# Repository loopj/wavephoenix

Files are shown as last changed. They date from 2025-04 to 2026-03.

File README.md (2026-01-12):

<h1 align="center">
    WavePhoenix
</h1>

<p align="center">
    Open-source implementation of the Nintendo WaveBird receiver using Silicon Labs Wireless Gecko SoCs
</p>
<p align="center">
    
</p>

<p align="center">
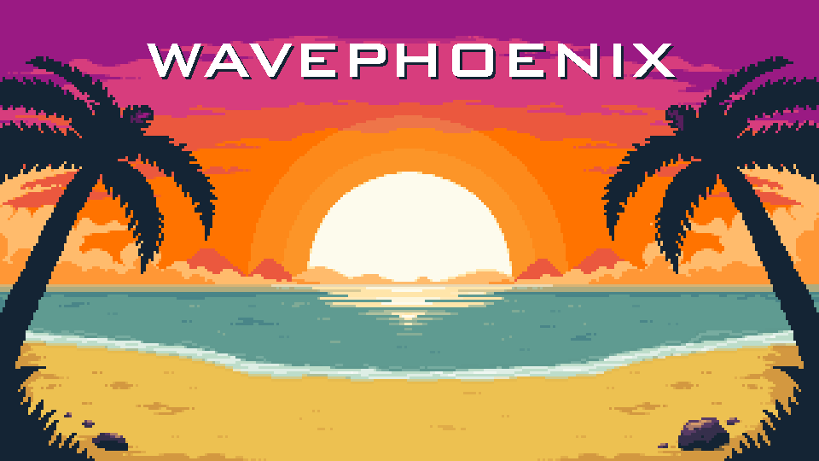
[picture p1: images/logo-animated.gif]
WavePhoenix
    
</p>

## Motivation

The WaveBird controller is, in my opinion, one of the best controllers ever made. It is wireless, has an insane battery life, and is very comfortable to hold. The WaveBird set a new standard for wireless controllers. It was the first major console controller to use radio frequency (RF) technology, providing a reliable, lag-free connection that didn't require line-of-sight, unlike infrared controllers.

Unfortunately, Nintendo stopped producing the WaveBird more than a decade ago, causing a dwindling supply of controllers and, especially, receivers. Given the decreasing supply of receivers and the increasing resale prices, I decided to design my own from scratch.

## Features

The reference implementation of WavePhoenix includes the following features:

- Full compatibility with the original WaveBird controller
- One-button virtual pairing, like modern wireless devices
- Status LED to indicate pairing status and radio activity
- Over-the-air firmware updates via Bluetooth
- Open source hardware and firmware
- 3D printable case

## Buying a WavePhoenix

Don't want to build your own? A number of vendors are now selling pre-assembled WavePhoenix receivers!

- [Laser Bear Industries](https://www.laserbear.net/products/wavephoenix-replacement-wavebird-gamecube-receiver) - US-based seller, custom enclosure and PCB by Greg
- [Colester Productions](https://shop.colesterproductions.com/product/wave-phoenix) - US-based seller, uses my original PCB and [
SadSnifit's fantastic case](https://makerworld.com/en/models/1463984-wavephoenix-wavebird-shell)
- [Various AliExpress sellers](https://www.aliexpress.us/w/wholesale-%22wavephoenix%22.html)

## Building a WavePhoenix

The bare minimum hardware needed to build a WavePhoenix is a EFR32BG22 radio module (such as the [RF-BM-BG22C3](https://www.rfstariot.com/rf-bm-bg22c3-efr32bg22-bluetooth-module_p93.html)), a GameCube controller connector, and 3 wires!

Since most people prefer a more streamlined solution, I designed a custom PCB and 3D-printable case called the *Mini Receiver*.

You can find detailed build instructions in the [hardware/mini-receiver](hardware/mini-receiver) directory.

## Firmware Components

The firmware for WavePhoenix is composed of the following components:

- [`libwavebird`](https://github.com/loopj/libwavebird) - my implementation of Nintendo's WaveBird protocol for Silicon Labs Gecko SoCs
- [`libjoybus`](https://github.com/loopj/libjoybus) - my implementation of the Joybus protocol used by N64 and GameCube controllers
- [`firmware/app`](firmware/app) - the main app firmware; a reference implementation of a WaveBird receiver
- [`firmware/bootloader`](firmware/bootloader) - bootloader to provide over-the-air firmware updates via Bluetooth

## Worklog

Check out the [worklog](WORKLOG.md) for a detailed history of the development of the WavePhoenix project.

## Special Thanks

- [Sam Edwards](https://github.com/CFSworks) for his incredible WaveBird reverse engineering documentation, which was essential in getting this working
- [Jeff Longo](https://jefflongo.dev) - for his detailed GameCube controller protocol documentation
- [Aurelio Mannara](https://github.com/Aurelio92) - for open sourcing GC+, another great reference for the GameCube controller protocol
- [YveltalGriffin](https://bsky.app/profile/mks.bsky.social) - for help and advice along the way, and helping me figure out those mysterious origin packets
- piotref1 - for being the very first person to build a WavePhoenix receiver and provide feedback, a true early adopter!
- Everyone in the incredible [BitBuilt community](https://bitbuilt.net/) for their support and encouragement throughout this project

## License

WavePhoenix is a permissively licensed open source project.

The firmware is licensed under the [MIT License](firmware/LICENSE).

The hardware is licensed under the [Solderpad Hardware License v2.1](hardware/LICENSE).

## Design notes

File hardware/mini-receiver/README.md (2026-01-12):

# WavePhoenix Mini Receiver

The WavePhoenix Mini Receiver is a small, low-cost WaveBird receiver replacement. It has been designed to be as cheap as possible (~$4 in parts) and simple to build.

The receiver uses a cheap, off-the-shelf wireless module (the [RF-BM-BG22C3](https://www.rfstariot.com/rf-bm-bg22c3-efr32bg22-bluetooth-module_p93.html)), which can either be hand-wired, or assembled onto a custom PCB.

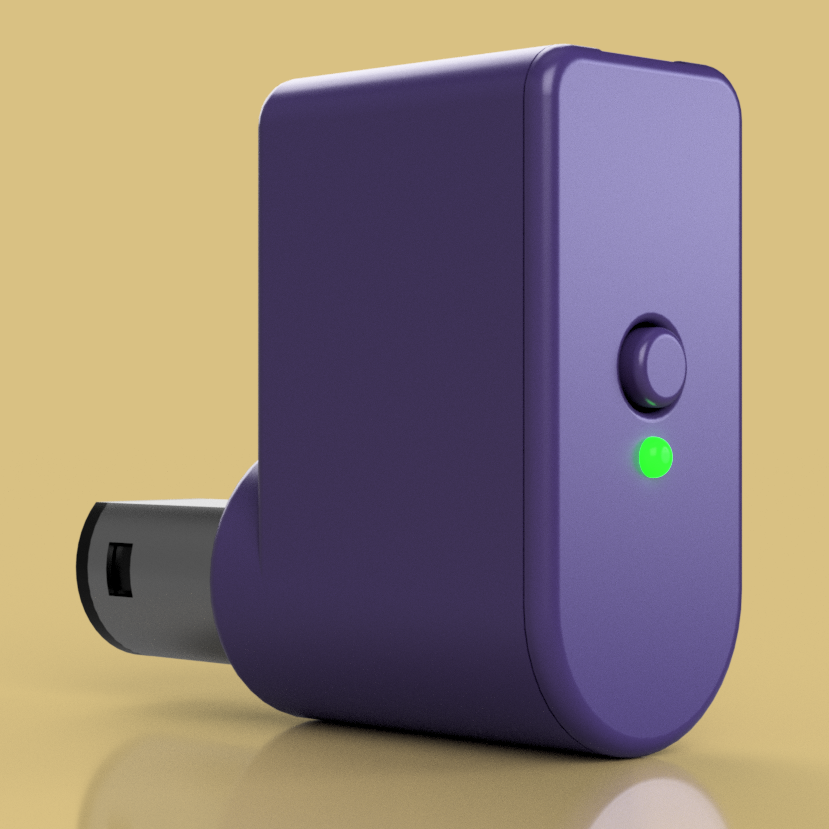
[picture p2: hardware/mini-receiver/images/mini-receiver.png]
WavePhoenix Mini Receiver
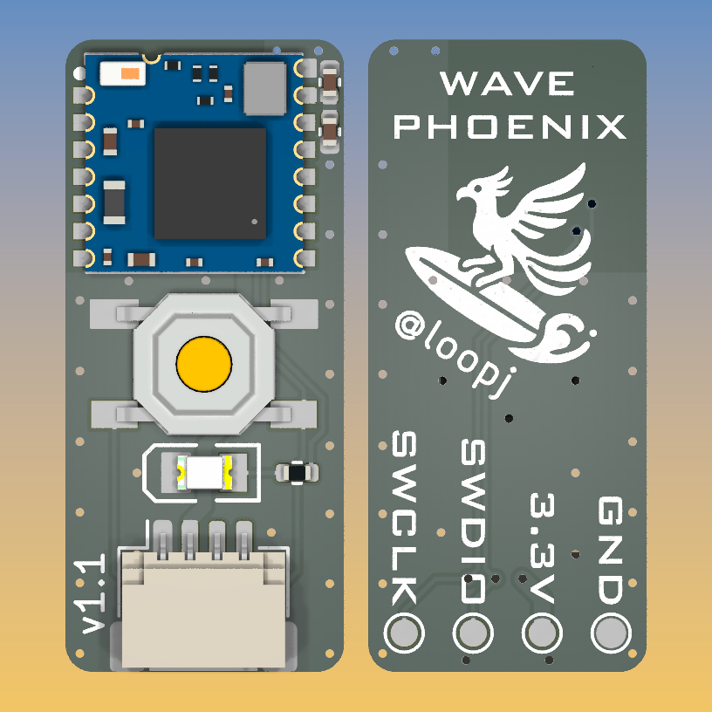
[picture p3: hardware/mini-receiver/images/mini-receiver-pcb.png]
WavePhoenix Mini Receiver
 

## Build Guide

### Parts

- Assembled Mini Receiver PCB - (see [PCB](#pcb))
- 3D printed case - (see [Case](#case))
- GameCube male connector - ([AliExpress](https://www.aliexpress.us/item/3256804501860592.html), [Alibaba](https://www.alibaba.com/product-detail/NGC-Gamecube-Male-Connector_1600107604838.html), [eBay](https://www.ebay.com/itm/354372477064))
- JST-SH 4-Pin connector with pre-crimped cable - ([AliExpress](https://www.aliexpress.us/item/3256803952186380.html), [Amazon](https://www.amazon.com/dp/B0D9WMLZ7B/))
- 1.5mm PMMA fiber cable - ([AliExpress](https://www.aliexpress.us/item/3256806278563564.html)) *or* 1.5mm diameter x 4mm light pipe - ([AliExpress](https://www.aliexpress.us/item/3256801194682892.html))
- Crimping tool or soldering iron (depending on the your connector type)

### Assembly

- Assemble the JST-SH to GameCube connector cable - (see [Cable](#cable))
- Flash the firmware - (see [Initial Firmware Flashing](#initial-firmware-flashing))
- Insert the GameCube connector into the case until it clicks into place
- Connect the JST-SH connector to the PCB
- Insert the PCB into the case, ensuring the LED and switch are aligned with the holes in the case, it should click into place
- Insert the light pipe into the small hole in the front of the case, if using PMMA fiber for the light pipe, cut it to size first (4mm)
- Insert the 3D printed button into the large hole in the front of the case
- Press the front of the case onto the back of the case

## PCB

The WavePhoenix Mini Receiver PCB is a simple carrier PCB for a RF-BM-BG22C3 module, tact switch, status LED, and a connector for the GameCube controller port.

### Ordering from JLCPCB, PCBWay, etc

You can find the gerber files in the [`gerbers`](gerbers) directory.

Order the PCB with the following settings:

- 2-layer board
- PCB thickness of 1.2mm
- HASL is fine

### Bill of Materials

- 1x RF-BM-BG22C3 module ([AliExpress](https://www.aliexpress.us/item/3256804772492081.html), [LCSC](https://www.lcsc.com/product-detail/Bluetooth-Modules_RF-star-RF-BM-BG22C3_C5369196.html), [Tindie](https://www.tindie.com/products/rfstariot/small-size-efr32bg22-wireless-transceiver/))
- 1x 0805 green LED
- 1x 5x5mm tactile switch
- 1x 4-pin JST-SH connector
- 1x 0402 100Ω resistor (adjust as needed)
- 1x 0402 10uF capacitor
- 1x 0402 0.1uF capacitor

You can find a [Mouser shared cart here](https://www.mouser.com/ProjectManager/ProjectDetail.aspx?AccessID=66aed3ee61). You'll need to source the RF-BM-BG22C3 module separately.

You can find an [interactive BOM here](ibom.html).

### Hand Assembly

The components should all be hand solderable, the smallest parts being the 0402 capacitors and resistor. If you are struggling with the capacitors, you can omit them, but it is recommended to include them.

I recommend using magnification, and soldering the RF-BM-BG22C3 module first, since the module is hard to solder once the capacitors are in place.

### PCB Assembly Services

If you want to use a PCB assembly service such as JLC PCBA, the CPL file and the BOM file are also found in the [`gerbers`](gerbers) directory.

Unfortunately the RF-BM-BG22C3 module is not available for JLC's awesome economic assembly, so you will either need to pay for the standard assembly, or hand solder the module yourself.

## Case

I highly recommend you use [SadSnifit's WavePhoenix shell](https://makerworld.com/en/models/1463984-wavephoenix-wavebird-shell) for the case, it is very well designed and looks great.

Alternatively, my original 3D printable case for the receiver can be found in the [`case`](case) directory.

## Cable

> [!TIP]
> The [Fires Custom Controller](https://firescc.com/mod-guides#/diy-custom-cables) custom cable guide, covers the crimping the GameCube connector pins in detail!

Although we are using a 4-pin JST-SH connector, we only actually need 3 wires for the receiver. In the following photos, the ground wire is black, the power wire is red, and the data wire is blue, however the wire colors of pre-made JST cables vary *wildly*, so please check the pinout rather than relying on the wire colors in the photos.

Pin 1 on the JST-SH connector is indicated by a small triangle on the connector housing. In my photos below I have removed the unused wire from pin 4 of the JST-SH connector, but you can also leave it in place if you prefer.

First trim the wires on JST-SH connector cable to 30mm:

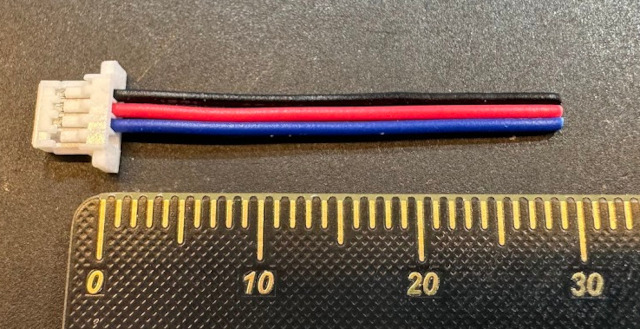
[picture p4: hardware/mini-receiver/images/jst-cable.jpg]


Strip a small amount of insulation (~1mm) off the ends of the wires, and crimp the wires to the GameCube connector pins.

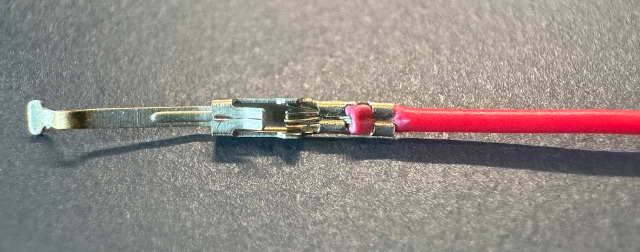
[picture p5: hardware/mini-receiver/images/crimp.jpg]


Insert the crimped pins into the GameCube connector housing in the following positions:

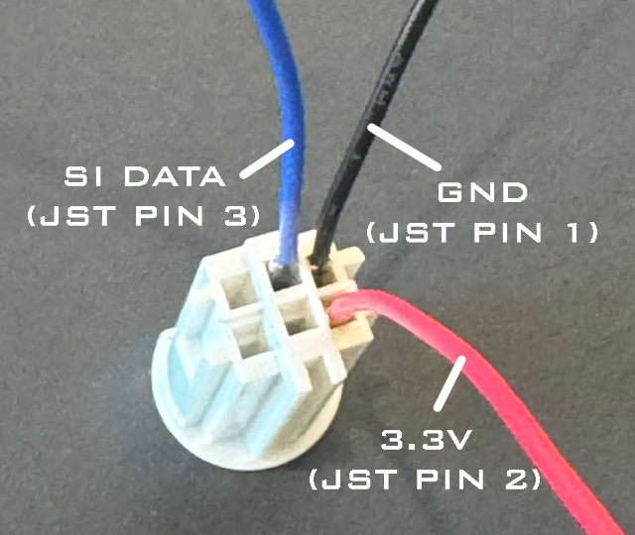
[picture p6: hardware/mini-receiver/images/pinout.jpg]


The “wings” on each pin should face towards the center of the plug, and the pins should be inserted until they click into place.

Next we need to trim off and file down the cable retention tabs on the metal GameCube connector housing:

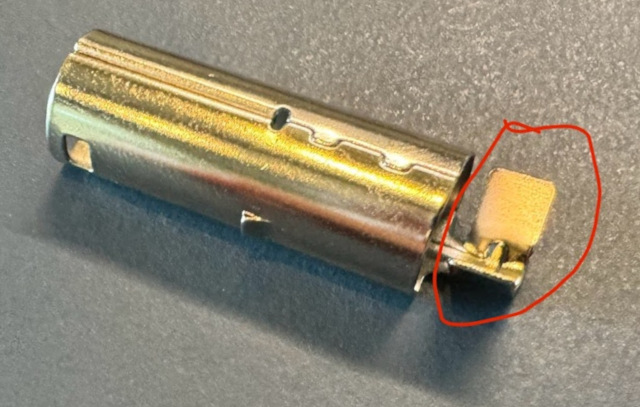
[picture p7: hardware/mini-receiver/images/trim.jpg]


We can then finally insert the plastic connector into the metal housing:

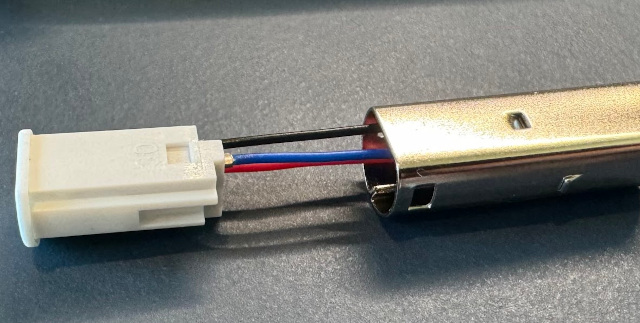
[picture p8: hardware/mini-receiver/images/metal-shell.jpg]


The complete assembly should look like this:

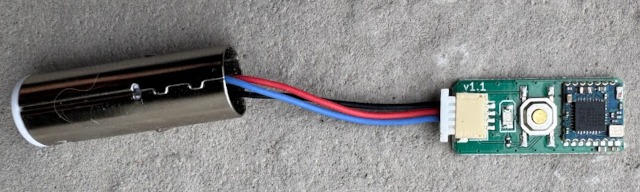
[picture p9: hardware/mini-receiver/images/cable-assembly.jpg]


## Initial Firmware Flashing

> [!NOTE]
> Once you have flashed the bootloader, you can use Bluetooth over-the-air updates to flash future firmware updates!

WavePhoenix receivers have two pieces of software running on them, the *bootloader* and the *application firmware*. The *bootloader* allows us to flash future application updates over Bluetooth, the *application firmware* is the program that handles WaveBird communication.

You can [find the latest bootloader and firmware here](https://github.com/loopj/wavephoenix/releases/latest), the mini-receiver needs the `rf-bm-bg22c3` build of the firmware.

The first-time flashing of the firmware requires a debug probe and some special software. If your WavePhoenix board already has the bootloader flashed, you can skip this part.

### Debug Probes

You'll need a SWD debug probe to flash the initial firmware onto the receiver. The debug probe connects to the receiver's SWD pins and allows you to flash the firmware using OpenOCD.

If you don't already have an SWD-capable debug probe, you can build one using a Raspberry Pi Pico. Instructions on how to build a debug probe using a Raspberry Pi Pico can be found in the [Appendix](#pi-pico-debug-probe).

### Pinouts

If you are flashing an assembled Mini Receiver board, the SWD pins are made available in two locations, pads on the back of the board, and via the 4-pin JST-SH connector.

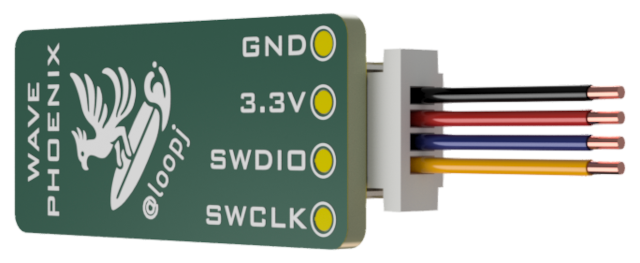
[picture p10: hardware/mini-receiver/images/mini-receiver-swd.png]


The pinout of the JST-SH connector is as follows:

| Pin | Function | Description |
| --- | --- | --- |
| 1 | GND | Ground |
| 2 | 3.3V | Power |
| 3 | SWDIO | SWD Data / GameCube Data |
| 4 | SWCLK | SWD Clock |

### OpenOCD

To flash the firmware, you'll need to install Arduino's fork of OpenOCD, which adds support for EFR32 Series 2 SoCs.

Prebuilt binaries are available for [Windows](https://downloads.arduino.cc/tools/openocd-0.12.0-arduino1-static-i686-w64-mingw32.tar.bz2), [macOS](https://downloads.arduino.cc/tools/openocd-0.12.0-arduino1-static-x86_64-apple-darwin19.tar.bz2), and [Linux](https://downloads.arduino.cc/tools/openocd-0.12.0-arduino1-static-x86_64-ubuntu16.04-linux-gnu.tar.bz2).

The source for this fork is available on [GitHub here](https://github.com/facchinm/OpenOCD/tree/arduino-0.12.0-rtx5).

### Flashing

Once you have OpenOCD installed, you can flash the bootloader and application firmware using the following commands:

#### Erase the device

First we'll need to do a full device erase:

```bash
# Linux / macOS
openocd -f "interface/cmsis-dap.cfg" \
        -f "target/efm32s2.cfg" \
        -c "init; efm32s2_dci_device_erase; shutdown"
```

```powershell
# Windows (PowerShell)
openocd.exe -f "interface\cmsis-dap.cfg" `
            -f "target\efm32s2.cfg" `
            -c "init; efm32s2_dci_device_erase; shutdown"
```

> [!IMPORTANT]  
> Disconnect then reconnect the debug probe to the receiver before proceeding to the next step.

#### Flash the bootloader

Then we can flash the bootloader:

```bash
# Linux / macOS
openocd -f "interface/cmsis-dap.cfg" \
        -c "transport select swd" \
        -f "target/efm32s2.cfg" \
        -c "init; halt; flash write_image erase bootloader.hex; exit"
```

```powershell
# Windows (PowerShell)
openocd.exe -f "interface\cmsis-dap.cfg" `
            -c "transport select swd" `
            -f "target\efm32s2.cfg" `
            -c "init; halt; flash write_image erase bootloader.hex; exit"
```

> [!TIP]  
> From this point on, you can now use Bluetooth over-the-air updates to flash new application firmware!

#### Flash the application

Since we already have the device wired up, we can also flash the receiver application using SWD:

```bash
# Linux / macOS
openocd -f interface/cmsis-dap.cfg \
        -c "transport select swd" \
        -f target/efm32s2.cfg \
        -c "init; halt; flash write_image erase receiver.hex; exit"
```

```powershell
# Windows
openocd.exe -f interface\cmsis-dap.cfg `
            -c "transport select swd" `
            -f target\efm32s2.cfg `
            -c "init; halt; flash write_image erase receiver.hex; exit"
```

You should now have a fully functional WavePhoenix receiver!

## Usage

### Pairing

WavePhoenix receivers use "virtual pairing" instead of the original WaveBird’s channel wheel. To initiate pairing, press the receiver’s pairing button. The onboard LED will start blinking to indicate the receiver is now in pairing mode. Press and hold X + Y on the WaveBird controller to pair a WaveBird to a receiver. Once pairing is successful, the LED will stop blinking and remain solid.

### Entering Bootloader Mode

You can enter the bootloader for OTA updates in two ways:

1. Press and hold the pairing button for more than 3 seconds, until the LED turns off
2. Press and hold the pairing button while plugging in the receiver

### Upgrading Firmware

You can always find the latest receiver firmware in the [latest release](https://github.com/loopj/wavephoenix/releases/latest) on GitHub. The firmware is available in two formats, a `.gbl` file for over-the-air updates, and a `.hex` file for flashing via SWD.

The mini receiver uses the `rf-bm-bg22c3` build of the firmware, which is specifically designed for the RF-BM-BG22C3 module.

#### Using WavePhoenix Web

If you have a computer with Bluetooth or an Android phone, you can use [WavePhoenix Web](https://web.wavephoenix.com) in Google Chrome to flash the firmware.

#### Flashing via SWD

You can also always use SWD to re-flash the firmware, as described in the [Initial Firmware Flashing](#initial-firmware-flashing) section.

## Appendix

### Pi Pico Debug Probe

If you have a Raspberry Pi Pico, you can use it as a debug probe to flash WavePhoenix firmware. The Pico is a low-cost (~$4) microcontroller board that can be used as a debug probe with OpenOCD.

Download the latest `debugprobe_on_pico.uf2` from the [Raspberry Pi Debug Probe repo](https://github.com/raspberrypi/debugprobe/releases/latest) and flash it to your Pico by dragging the file onto the Pico's USB drive. Once you have flashed the firmware, the Pico will now be available to use as a debug probe with OpenOCD.

Here's the pinout for SWD programming:

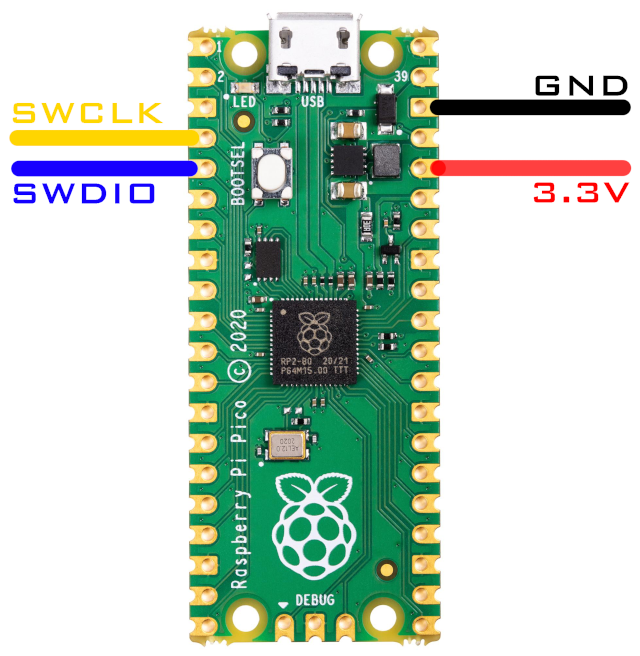
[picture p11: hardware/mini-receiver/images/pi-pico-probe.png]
Pi Pico Debug Probe


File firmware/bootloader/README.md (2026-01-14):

# WavePhoenix Bootloader

## Dependencies

- [GNU Arm Embedded Toolchain](https://developer.arm.com/Tools%20and%20Software/GNU%20Toolchain)
- [Silicon Labs Simplicity SDK](https://github.com/SiliconLabs/simplicity_sdk)
- [Silicon Labs Configurator (SLC-CLI)](https://www.silabs.com/software-and-tools/simplicity-studio/configurator-command-line-interface) (requires Java)

## Configuration

You'll need to tell SLC-CLI where your Simplicity SDK and ARM toolchain are located:

```bash
slc configuration --sdk path/to/simplicity_sdk
slc configuration --gcc-toolchain path/to/gcc-arm-none-eabi
slc signature trust --sdk path/to/simplicity_sdk
```

## Building

To build the WavePhoenix bootloader, run the following script, replacing `rf-bm-bg22c3` with your target board:

```bash
BOARD=rf-bm-bg22c3 ./build.sh
```

This will generate `target/rf-bm-bg22c3/build/release/bootloader.hex`.

## Flashing

### Using Simplicity Commander

If you are using a dev board with a built-in J-Link debugger, you can use Simplicity Commander to flash the bootloader:

```bash
commander flash bootloader.hex
```

### Using OpenOCD

If you are using a generic SWD debug probe, you can use OpenOCD to flash the bootloader:

1. Download and install Arduino's fork of OpenOCD ([Windows](https://downloads.arduino.cc/tools/openocd-0.12.0-arduino1-static-i686-w64-mingw32.tar.bz2), [macOS](https://downloads.arduino.cc/tools/openocd-0.12.0-arduino1-static-x86_64-apple-darwin19.tar.bz2), [Linux](https://downloads.arduino.cc/tools/openocd-0.12.0-arduino1-static-x86_64-ubuntu16.04-linux-gnu.tar.bz2))

2. Connect GND, SWDIO, SWCLK, and 3V3 between the debug probe and the SoC.

3. If this is your first time flashing this chip, you'll need to do a full device erase to unlock the debug interface:

      ```bash
      openocd -f "interface/cmsis-dap.cfg" \
              -f "target/efm32s2.cfg" \
              -c "init; efm32s2_dci_device_erase; shutdown"
      ```

4. Disconnect then reconnect the debug probe.

5. Then, flash the bootloader, replacing `bootloader.hex` with the path to your bootloader file:

    ```bash
    openocd -f interface/cmsis-dap.cfg \
          -c "transport select swd" \
          -f target/efm32s2.cfg \
          -c "init; halt; flash write_image erase bootloader.hex; exit"
    ```

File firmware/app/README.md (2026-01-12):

# WavePhoenix App Firmware

## Dependencies

- [GNU Arm Embedded Toolchain](https://developer.arm.com/Tools%20and%20Software/GNU%20Toolchain)
- [Silicon Labs Simplicity SDK](https://github.com/SiliconLabs/simplicity_sdk)
- [Silicon Labs Configurator (SLC-CLI)](https://www.silabs.com/software-and-tools/simplicity-studio/configurator-command-line-interface) (requires Java)
- [Simplicity Commander](https://www.silabs.com/developers/simplicity-studio/simplicity-commander?tab=downloads) (optional, required to generate OTA binaries)

## Configuration

You'll need to tell SLC-CLI where your Simplicity SDK and ARM toolchain are located:

```bash
slc configuration --sdk path/to/simplicity_sdk
slc configuration --gcc-toolchain path/to/gcc-arm-none-eabi
slc signature trust --sdk path/to/simplicity_sdk
```

## Building

To build the WavePhoenix app, run the following script, replacing `rf-bm-bg22c3` with your target board:

```bash
BOARD=rf-bm-bg22c3 ./build.sh
```

This will generate:

- `target/rf-bm-bg22c3/build/release/wavephoenix.hex` - The firmware binary for SWD flashing
- `target/rf-bm-bg22c3/build/release/wavephoenix.gbl` - The firmware binary for OTA flashing

## Flashing

> [!IMPORTANT]
> A bootloader **must** be installed before flashing the app firmware. See the [`bootloader`](../bootloader) directory for more information.

### Over-the-air (OTA) flashing

If you have a computer or phone with Bluetooth, you can use [WavePhoenix Web](https://web.wavephoenix.com) to flash the firmware.

### Using Simplicity Commander

If you are using a dev board with a built-in J-Link debugger, you can use Simplicity Commander to flash the firmware:

```bash
commander flash wavephoenix.hex
```

### Using OpenOCD

If you are using a generic SWD debug probe, you can use OpenOCD to flash the firmware:

1. Download and install Arduino's fork of OpenOCD ([Windows](https://downloads.arduino.cc/tools/openocd-0.12.0-arduino1-static-i686-w64-mingw32.tar.bz2), [macOS](https://downloads.arduino.cc/tools/openocd-0.12.0-arduino1-static-x86_64-apple-darwin19.tar.bz2), [Linux](https://downloads.arduino.cc/tools/openocd-0.12.0-arduino1-static-x86_64-ubuntu16.04-linux-gnu.tar.bz2))

2. Connect GND, SWDIO, SWCLK, and 3V3 between the debug probe and the SoC
3. Flash the firmware, replacing `wavephoenix.hex` with the path to your firmware file:

    ```bash
    openocd -f interface/cmsis-dap.cfg \
          -c "transport select swd" \
          -f target/efm32s2.cfg \
          -c "init; halt; flash write_image erase wavephoenix.hex; exit"
    ```

## Customizing the firmware

The WavePhoenix firmware can be customized by setting various flags in board configuration files. See the [`boards`](../boards) folder for examples.

### Joybus Configuration

The Joybus GPIO is the communication line between the WavePhoenix and the console, and is **required** for WavePhoenix to function.

Define the following:

- `JOYBUS_PORT` - The GPIO port for the SI data line (e.g. `gpioPortD`)
- `JOYBUS_PIN` - The GPIO pin for the SI data line (e.g. `3`)
- `JOYBUS_TIMER` - The timer peripheral to use in `libjoybus` (e.g. `TIMER0`)
- `JOYBUS_USART` - The USART peripheral to use in `libjoybus` (e.g. `USART0`)

### Status LED

The WavePhoenix receiver firmware supports an optional status LED. The LED will blink on radio activity, just like the original WaveBird receiver. The LED will also indicate pairing status in virtual pairing mode.

To enable the optional status LED, define the following:

- `HAS_STATUS_LED` - Set to `1` to enable status LED support
- `STATUS_LED_PORT` - The GPIO port for the status LED
- `STATUS_LED_PIN` - The GPIO pin for the status LED
- `STATUS_LED_INVERT` - Set to `1` to invert the LED logic (i.e. LED on when GPIO is low)

### Pairing button

The WavePhoenix receiver firmware supports a one-button "virtual pairing" mode. Connect one side of a switch to a GPIO, and the other side to ground. When the button is pressed, the receiver will enter pairing mode. Pressing and holding buttons on the controller will cause the receiver to pair with the controller. The exact behavior is
customizable by passing a pairing qualification function to `wavebird_radio_configure_qualification`.

To enable the pairing button, define the following:

- `HAS_PAIR_BTN` - Set to `1` to enable pairing button support
- `PAIR_BTN_PORT` - The GPIO port for the pairing button
- `PAIR_BTN_PIN` - The GPIO pin for the pairing button

### Channel wheel

The WavePhoenix receiver firmware supports an optional 16-position channel selection wheel, just like the original WaveBird receiver. The channel wheel is a rotary DIP switch with 4 data pins, and one common pin. The common pin should be connected to ground, and the data pins should be connected to GPIOs.

Due to the way interrupts work on EFR32 devices, the pin numbers must be different for each channel wheel pin, even if they are on the different ports.

To enable the optional channel selection wheel, define the following:

- `HAS_CHANNEL_WHEEL` - Set to `1` to enable channel wheel support
- `CHANNEL_WHEEL_PORT_0` - The GPIO port for the first channel wheel pin
- `CHANNEL_WHEEL_PIN_0` - The GPIO pin for the first channel wheel pin
- `CHANNEL_WHEEL_PORT_1` - The GPIO port for the second channel wheel pin
- `CHANNEL_WHEEL_PIN_1` - The GPIO pin for the second channel wheel pin
- `CHANNEL_WHEEL_PORT_2` - The GPIO port for the third channel wheel pin
- `CHANNEL_WHEEL_PIN_2` - The GPIO pin for the third channel wheel pin
- `CHANNEL_WHEEL_PORT_3` - The GPIO port for the fourth channel wheel pin
- `CHANNEL_WHEEL_PIN_3` - The GPIO pin for the fourth channel wheel pin

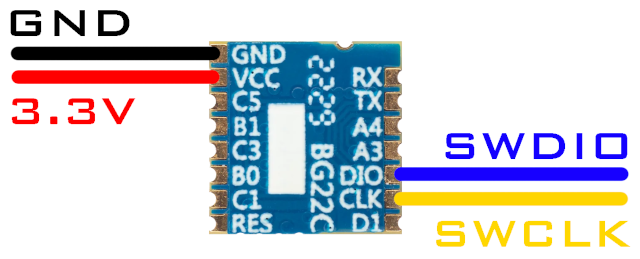
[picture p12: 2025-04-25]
hardware/mini-receiver/images/rf-bm-bg22c3.png

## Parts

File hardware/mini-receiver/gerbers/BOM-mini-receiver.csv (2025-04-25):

Comment | Designator | Footprint | LCSC
0.1uF | C1 | C_0402_1005Metric | C1525
10uF | C2 | C_0402_1005Metric | C15525
Conn_01x04_MountingPin | J1 | JST_SH_SM04B-SRSS-TB_1x04-1MP_P1.00mm_Horizontal | C160404
0805G (Green) | D1 | LED0805-R-RD | C2297
100R | R1 | R_0402_1005Metric | C25076
TS-1187A-B-A-B | SW1 | SW-SMD_4P-L5.1-W5.1-P3.70-LS6.5-TL-2 | C318884
RF-BM-BG22C3 | U1 | WIFI-SMD_15P-P1.00-L8.0-W8.0-P1.00_RF-BM-BG22C3 | C5369196

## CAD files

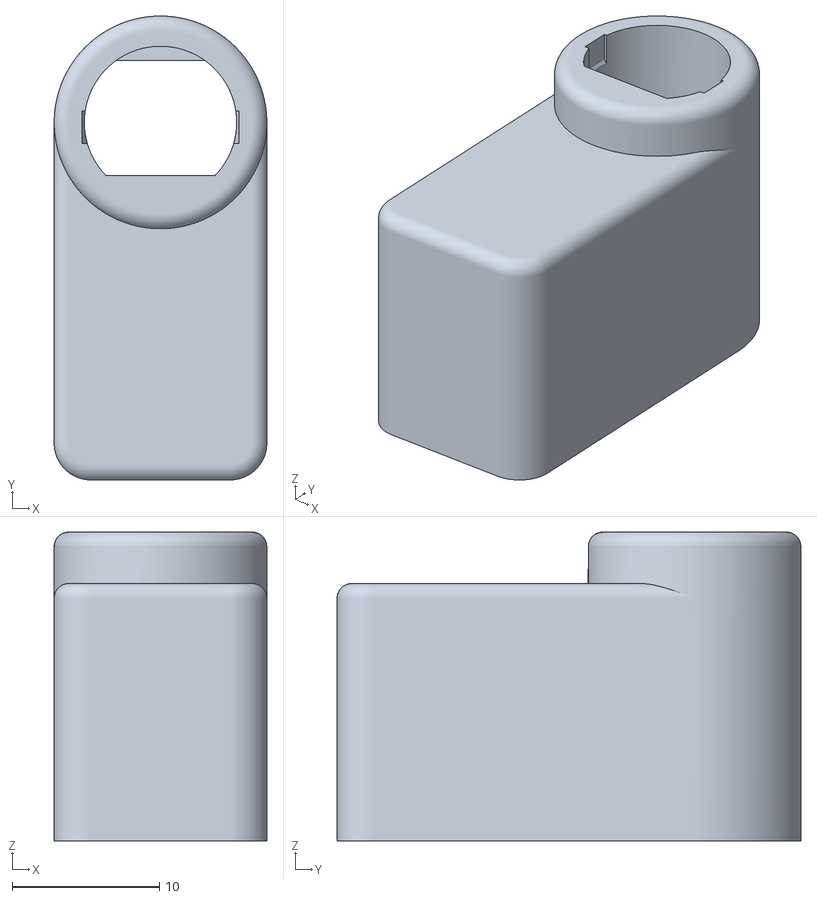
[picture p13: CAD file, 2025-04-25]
hardware/mini-receiver/case/Main Case.stl
14.5 x 31.5 x 21.0

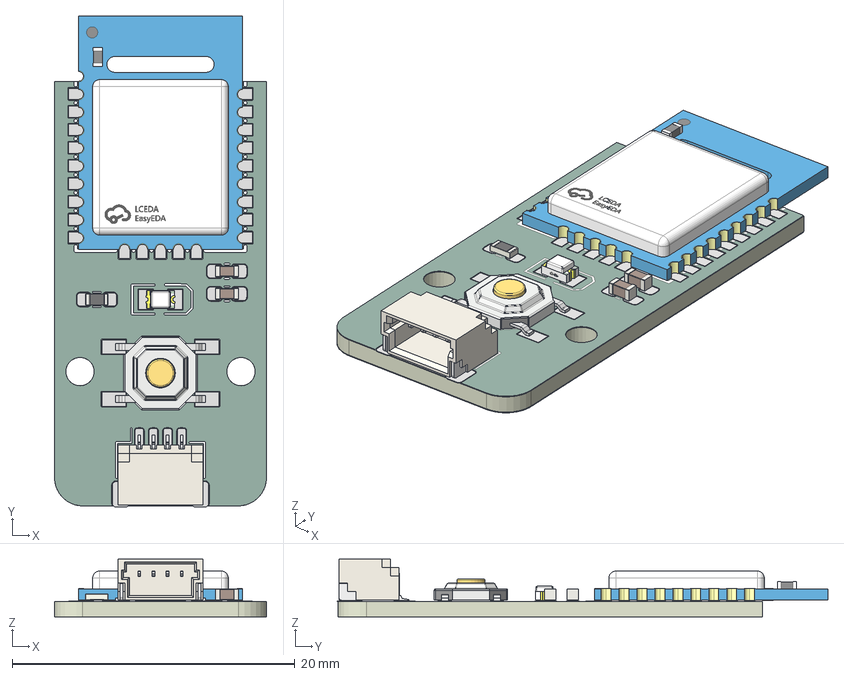
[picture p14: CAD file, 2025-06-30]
hardware/mini-receiver-bg22a3/KiCad/mini-receiver.step
15.0 x 34.7 x 4.14 mm
CONN-SMD_SR1.00-WS-4P
C_0603_1608Metric x 2
LED0805-RD
KEY-SMD_4P-L5.2-W5.2-H1.5-LS6.4-P3.70
R_0603_1608Metric
RF-BM-BG22A3
mini-receiver_pad
mini-receiver_silkscreen
mini-receiver_soldermask
mini-receiver_PCB

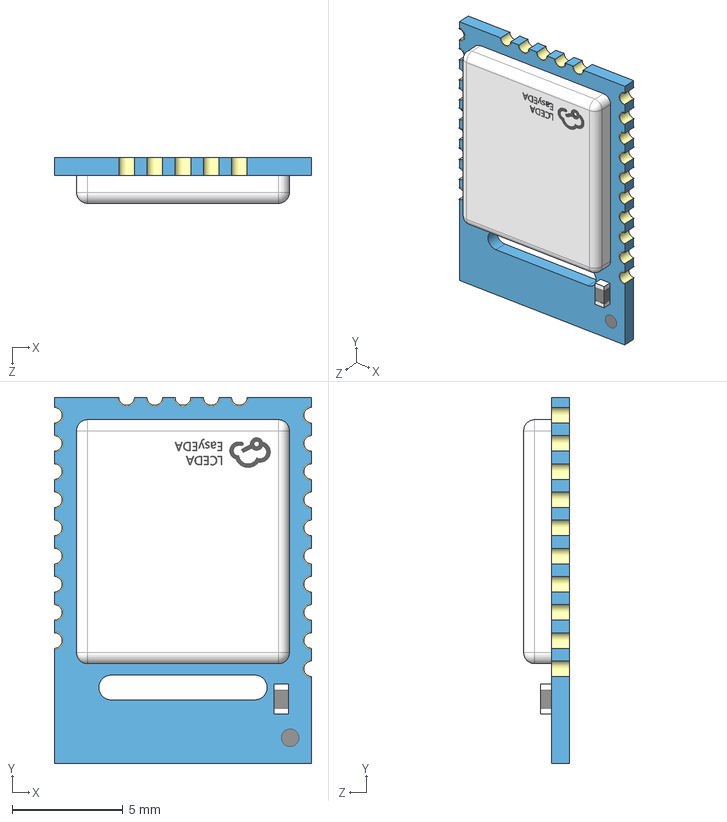
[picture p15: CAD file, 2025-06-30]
hardware/mini-receiver-bg22a3/KiCad/project-footprints/RF-BM-BG22A3.step
11.6 x 16.5 x 2.08 mm

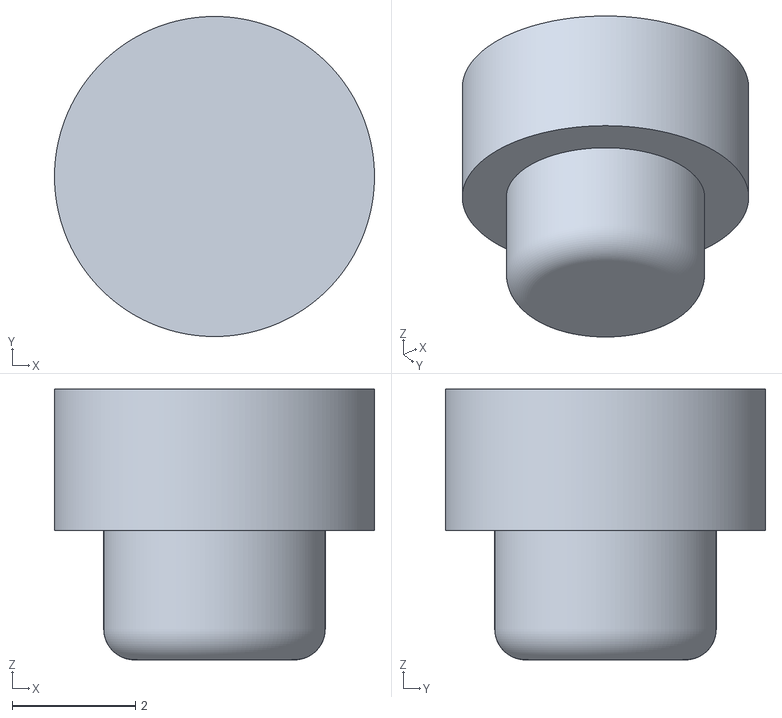
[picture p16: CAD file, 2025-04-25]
hardware/mini-receiver/case/Button Actuator.stl
5.20 x 5.20 x 4.40

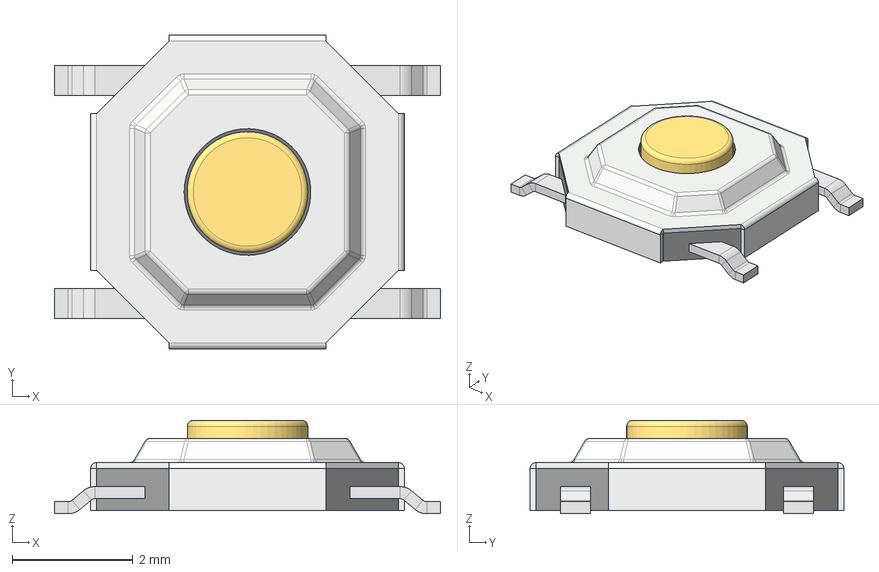
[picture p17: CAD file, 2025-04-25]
hardware/mini-receiver-bg22a3/KiCad/project-footprints/KEY-SMD_4P-L5.2-W5.2-H1.5-LS6.4-P3.70.step
6.40 x 5.20 x 1.55 mm

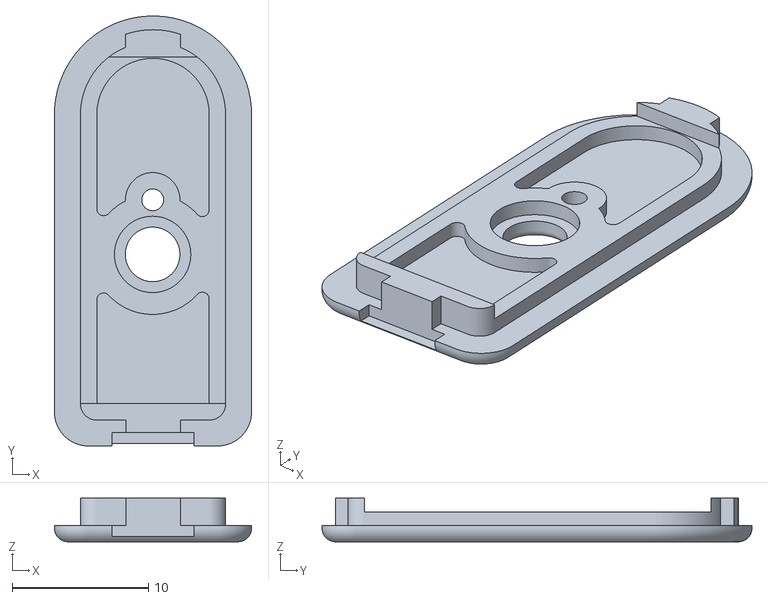
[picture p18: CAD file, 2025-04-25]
hardware/mini-receiver/case/Front Cover.stl
14.5 x 31.5 x 3.20

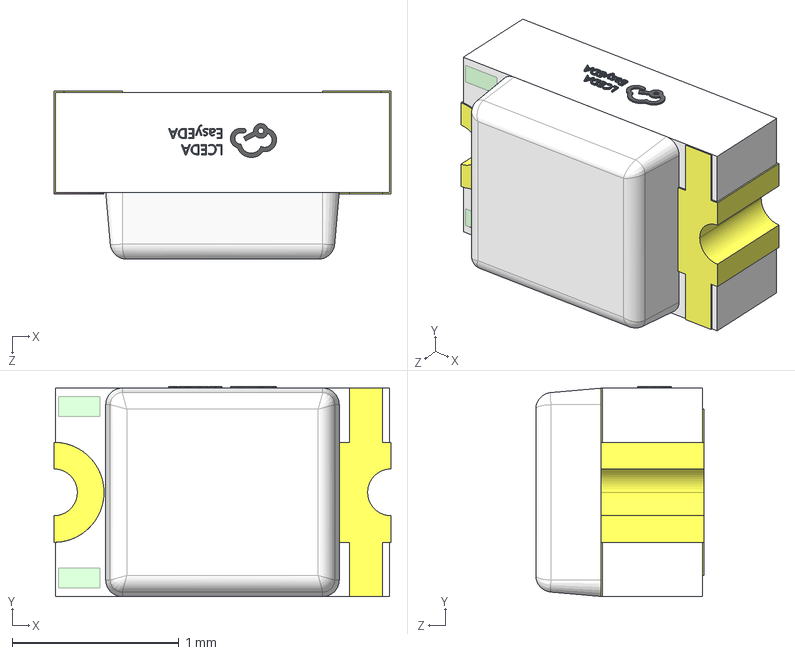
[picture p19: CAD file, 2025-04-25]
hardware/mini-receiver-bg22a3/KiCad/project-footprints/LED0805-RD.step
2.02 x 1.26 x 1.01 mm

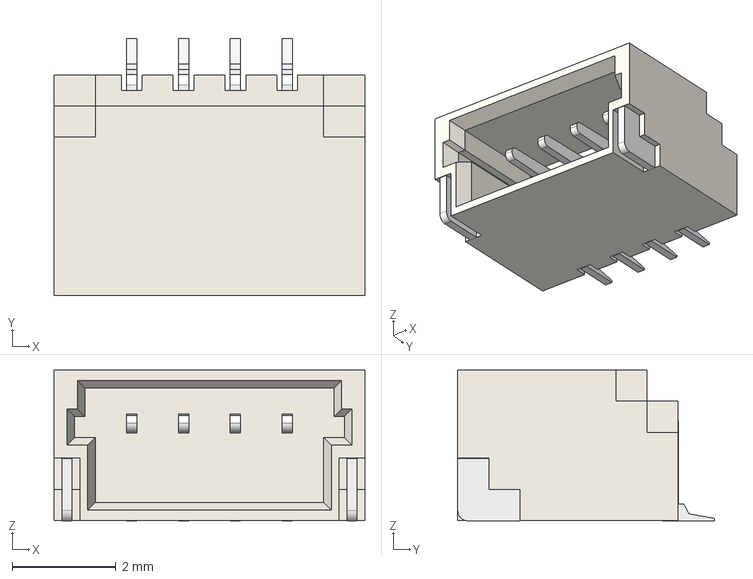
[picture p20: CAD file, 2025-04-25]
hardware/mini-receiver-bg22a3/KiCad/project-footprints/CONN-SMD_SR1.00-WS-4P.step
6.00 x 4.95 x 2.91 mm

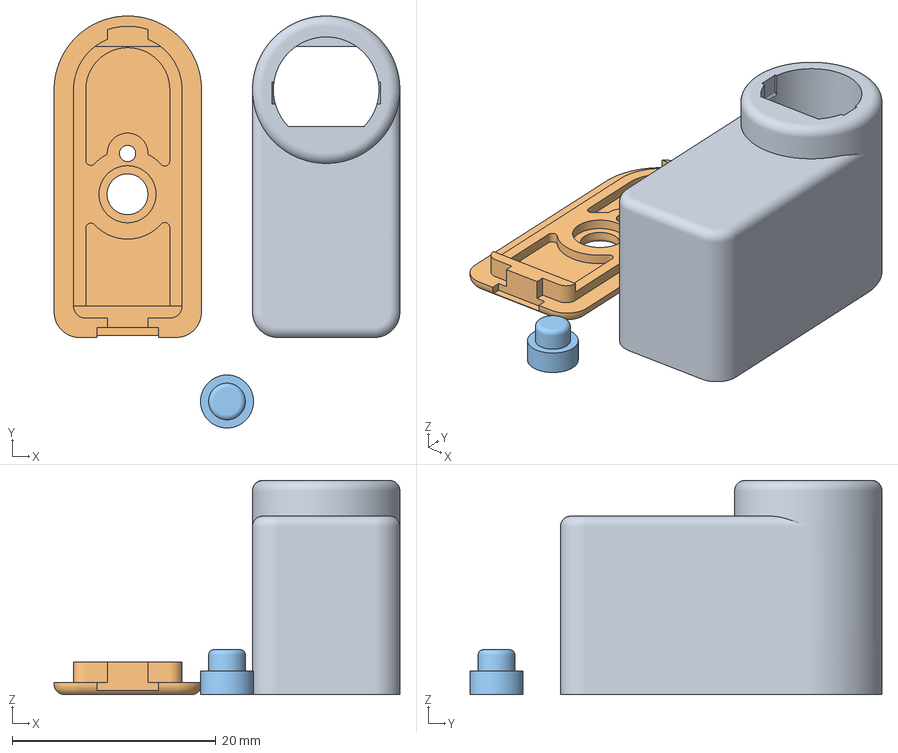
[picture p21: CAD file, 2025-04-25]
hardware/mini-receiver/case/WavePhoenix Mini Receiver.3mf
33.9 x 40.4 x 21.0 mm
Main Case.stl
Front Cover.stl
Button Actuator.stl

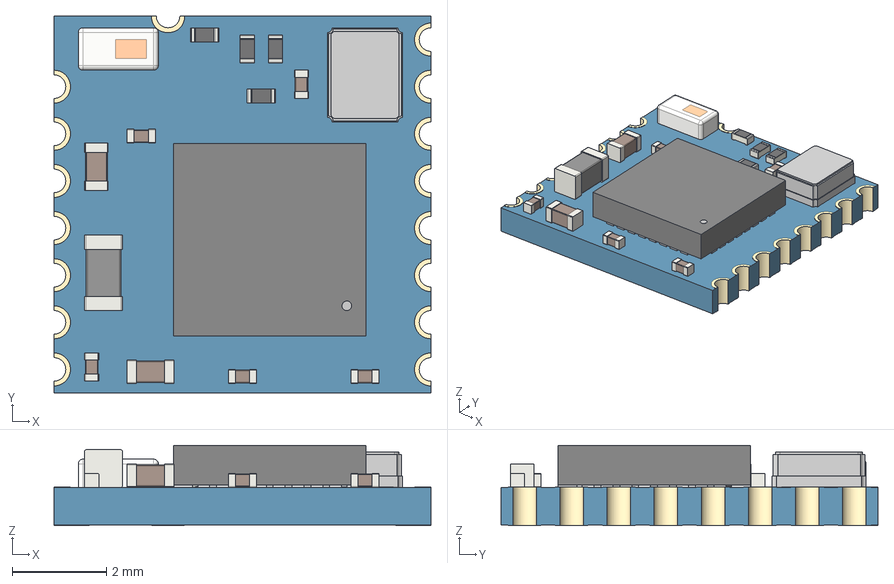
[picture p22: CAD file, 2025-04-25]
hardware/mini-receiver-bg22a3/KiCad/project-footprints/RF-BM-BG22C3.step
8.00 x 8.00 x 1.70 mm
Antenna
product
C_0201_0603Metric x 5
L_0603_1608Metric
C_0402_1005Metric x 2
R_0201_0603Metric x 4

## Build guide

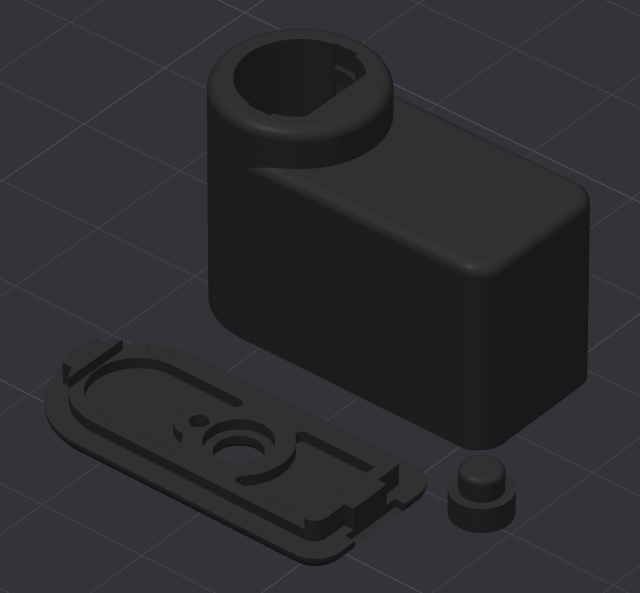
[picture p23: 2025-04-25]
hardware/mini-receiver/images/print-orientation.png

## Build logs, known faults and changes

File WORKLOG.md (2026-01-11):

# Development Worklog

## Finding an SoC

In mid-2020 I began researching the WaveBird protocol and came across Sam Edwards' incredibly well-written [WaveBird reverse-engineering](https://github.com/CFSworks/wavebird-reversing) documentation. Sam's docs aren't quite perfect, but they were **essential** in getting this working, thanks, Sam!

The most challenging part of this project was finding a wireless SoC that supported the specific modulation used by the WaveBird. What Sam describes in the [line coding and framing](https://github.com/CFSworks/wavebird-reversing/tree/master/05_line_coding_and_framing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) section of his document is actually a form of DSSS (Direct Sequence Spread Spectrum), one which uses *15 chips per bit*.

DSSS is a modulation technique that spreads the signal over a wide frequency band, making it more robust to interference and noise [here's a great breakdown by GeekyMuch](https://medium.com/networks-security/dsss-direct-sequence-spread-spectrum-a31005f281cc).

While it would certainly be possible to implement 15-chip DSSS demodulation using a software-defined radio, I wanted to find an SoC that could do this in hardware *in real-time*. After reading more datasheets than I care to admit, I discovered the [Silicon Labs Wireless Gecko EFR32FG1](https://www.silabs.com/wireless/proprietary/efr32fg1-series-1-sub-ghz-2-4-ghz-socs) family of SoCs, the [datasheet](https://www.silabs.com/documents/public/data-sheets/efr32fg1-datasheet.pdf) contains the magic incantation:

15 chip DSSS

Once I saw this, I had enough confidence to order a development kit and start working on the firmware.

> [!NOTE]
> Did you know that the codename for the GameCube CPU was *Gekko*? How fitting that we are using a *Gecko* SoC!

## Receiving and decoding packets

As I mentioned above, Sam's WaveBird reverse engineering documentation isn't *quite* right on a few things. Most importantly, I don't believe the DSSS chip length is accurate. After setting the DSSS chip length to 15 and configuring the many other radio settings, I got my first packet!

First packet

Decoding the packets was now simply a matter of writing some C code to de-interleave the packet, decode the [BCH(31,21)](https://en.wikipedia.org/wiki/BCH_code) messages, and perform the CRC check. After doing this, we finally had a decoded *input state* message containing the state of all the buttons and analog inputs on the controller!

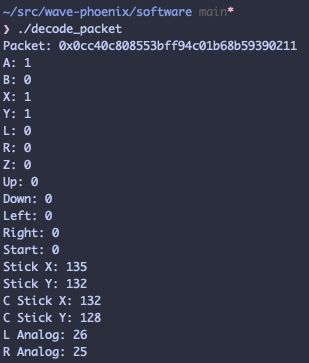
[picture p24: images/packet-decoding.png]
Packet decoding


But wait. Every now and then, I was getting a "corrupted" packet that somehow was still passing the CRC check. What could this be? It turns out that in addition to broadcasting *input state* messages 250 times per second, the WaveBird controller also broadcasts *origin* messages. These are sent as soon as the controller is powered on and then repeated every second after that. The origin message contains the state of the analog sticks when the console was powered on, which we'll need later.

## Communicating with a GameCube

Now we have real-time packet decoding; the next step is to send/receive commands on the *SI bus*. The SI bus is how GameCube/Wii consoles communicate with connected controllers. Jeff Longo has an insanely detailed and precise writeup about the [GameCube controller protocol](https://jefflongo.dev/posts/gc-controller-reverse-engineering-part-1/), which you should check out!

Bits are clocked in and out at speeds between 250kHz (wired OEM controllers) and 200kHz (consoles). To do this without tying up the CPU, I had to take full advantage of the peripherals on the EFR32 SoCs.

> [!NOTE]
> An OEM WaveBird receiver clocks data out at 225kHz, slightly slower than wired controllers!

### Listen for incoming commands

The first step is to listen for the various SI commands from the console.

To read these commands, we do the following:

- Configure a `TIMER` peripheral in capture/compare mode and attach it to the SI GPIO
- Connect the `TIMER` to an `LDMA` peripheral, filling the DMA buffer with 16 "edge timings" at a time
- Listen for a "DMA full" interrupt
- Determine the length of each "low" pulse by measuring the time between pairs of edges
- Based on the length of a low pulse, we store either a `0` or a `1` in our incoming byte buffer
- The first byte identifies the SI command type; this tells us how many bits to expect in the rest of the SI transmission
- Repeat until we have a complete SI command

### Replying to commands

Once we have a complete SI command, we need to respond (quickly!). We do this as follows:

- Use a `USART` peripheral to clock out pulses with precise timing without tying up the CPU
- Split each outgoing bit into 4 chips, so `0` becomes `0001`, `1` becomes `1110`, and stop becomes `0011`
- Configure the `USART` to output onto the SI GPIO, and set the baud rate to 1MHz (4 chips per bit @ 250kHz bitrate)
- Feed the chips into the `USART` transmit buffer, and wait for the "TX complete" interrupt to be triggered

### Command types

The most important command is the *get input state* command, which the console requests every frame. Since we should already have the latest input state packet from the WaveBird controller, we can simply send it back to the console after converting it to the SI format.

There are a bunch of other commands that we need to respond to, such as the *info* and *get origin* commands, but I'll leave that as an exercise for the reader to discover in the code.

## Wireless ID pinning

Since the WaveBird has no true concept of pairing, it is possible for multiple WaveBird controllers to be on the same channel at the same time. This is a problem, since the receiver will receive packets from all controllers on this channel. The WaveBird uses a simple "ID pinning" mechanism to solve this problem.

An OEM WaveBird receiver will look at the 10-bit controller ID present in all packets, and "fix" the ID to the first controller it receives a packet from.

## Channel selection

As well as supporting a channel wheel just like the original WaveBird receiver, I also wanted to add one-button "virtual pairing" support. This allows you to press a button on the receiver to enter pairing mode, and then hold a combination of buttons on a controller to "pair" it with the receiver. Under the hood, this scans through all 16 potential channels looking for wireless packets, and then checks if the appropriate buttons are being held on that channel.

## A more modern SoC

Although it doesn't explicitly call this out in the datasheet, I discovered that the EFR32xG22 series of SoCs *also* support 15-chip DSSS. This is great news since they are cheaper and more modern than the EFR32xG1 series. The EFR32BG22 SoC in particular has many pre-built modules which host the SoC, crystal, antenna, and RF matching network - such as the tiny [RF-BM-BG22C3 from RF-Star](https://www.rfstariot.com/rf-bm-bg22c3-efr32bg22-bluetooth-module_p93.html)

## Tuning, tuning, tuning

The hardest part of this project *by far* was tuning the radio settings.

The original WaveBird receiver has excellent range and wireless sensitivity. It is able to receive the full 250 packets per second at a distance of 10m+, so my goal was always to match this performance.

Dropping an occasional packet here and there is not a huge problem. Most GameCube games run at 60 frames per second so we have a little bit of leeway for the occasional dropped packet. However, if we drop too many packets this will result in missed inputs.

My initial radio configuration only managed to receive around 60 packets per second, so I spent a *lot* of time tuning the settings to get better performance. I'm now measuring 230+ packets per second at distances of around 5m, which is pretty close, and I think finally good enough to release.

I still think there is *a ton* of room for improvement here, pull requests would be very welcome!

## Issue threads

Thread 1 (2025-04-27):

PCB & import thoughts, and thanks!!

SL9M, 2025-04-27:
Hello loopj, congratulations on the release of this awesome project. I am honored to be first issue!

I have lots of these controllers and I've been waiting years to finally give them new life!

I ordered through JLC and I'm eagerly awaiting my batch! May be a while due to customs.

Couple thoughts:
- Are you interested in a gerber that includes larger pads for easier diy capacitor installation?

Those 2 at the top are slightly out of my comfort zone. A separate gerber with the caps either on the rear or relocated to be larger would help out with a no assembly order from places like OSH Park.

- Something like this probably would be a separate "Hand assembled" variation? _Like if it has to be soldered to the back._

- Thank you for your hard work on this!

SL9M, 2025-04-29:
To clarify, I'm interested in contributing to this project when the timing is favorable. Obtaining hardware just seemed like a logical first discussion.

Also, I am new to open source. I've been waiting for that **killer project that sparks motivation.**
I'd love to help with radio tuning, porting to other SOCs, providing support, etc.

Closed 2025-04-30.

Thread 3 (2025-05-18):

can't flash the firmware. I re-soldered several RF-BM-BG22C3 and they are all the same.

Cyrus331, 2025-05-18:
I don't know why I can't flash the firmware. I re-soldered several RF-BM-BG22C3 and they are all the same.

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

PS C:\openocd> openocd.exe -f "interface\cmsis-dap.cfg" `
>>             -f "target\efm32s2.cfg" `
>>             -c "init; efm32s2_dci_device_erase; shutdown"
Open On-Chip Debugger 0.12.0+dev-gc9fd9f6a2 (2024-11-03-02:11)
Licensed under GNU GPL v2
For bug reports, read
        http://openocd.org/doc/doxygen/bugs.html
Info : auto-selecting first available session transport "swd". To override use 'transport select <transport>'.
efm32s2_dci_read_se_status
Info : Using CMSIS-DAPv2 interface with VID:PID=0x2e8a:0x000c, serial=45474E621A0C499A
Info : CMSIS-DAP: SWD supported
Info : CMSIS-DAP: Atomic commands supported
Info : CMSIS-DAP: Test domain timer supported
Info : CMSIS-DAP: FW Version = 2.0.0
Info : CMSIS-DAP: Interface Initialised (SWD)
Info : SWCLK/TCK = 0 SWDIO/TMS = 0 TDI = 0 TDO = 0 nTRST = 0 nRESET = 0
Info : CMSIS-DAP: Interface ready
Info : clock speed 1000 kHz
Info : SWD DPIDR 0x6ba02477
Info : SWD DPIDR 0x6ba02477
Error: Failed to read memory at 0xe000ed00
Error: [efm32s2.cpu] Examination failed
Successfully connected to DCI
DCI WPENDING bit set, retrying
DCI SESTATUS response:
Debug lock (config): Enabled
Device erase: Enabled
Secure debug: Disabled
Debug lock (hw status): Enabled

 * * * * * * * * * * * * * * * * * * * * * * * * * * * * * * * * * * * *
  You will not be able to communicate with this device
  unless you perform a device erase (if available, indicated above)!
  Try efm32s2_dci_device_erase to attempt erase.
 * * * * * * * * * * * * * * * * * * * * * * * * * * * * * * * * * * * *

Warn : target efm32s2.cpu examination failed
Info : [efm32s2.cpu] starting gdb server on 3333
Info : Listening on port 3333 for gdb connections
Successfully connected to DCI
DCI WPENDING bit set, retrying
Device erase command sent. Device should now be erased and debug should be available again after a reset
shutdown command invoked

Closed 2025-05-30.

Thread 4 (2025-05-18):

Issues connecting to module in  openocd (windows)

DeputyDingles, 2025-05-18:
I should preface this by saying I am pretty new to programing modules and have never used openocd before (I am likely doing something wrong). When i attempt to erase the device I get this error ( **Error: Error connecting DP: cannot read IDR** ). I have tried flashing a module not attached to the board with wires directly soldered to the chip and have the same problem.  I have also resorted soldering wires direct to the receiver board and the debug probe to rule out a connection issue.  Below are pictures of how i am launching openocd and everything else (Yes i know the module is slightly crooked but i have verified that all connections are correct via microscope)

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

giuliooooooo, 2025-05-21:
Hi,
I had the same issue on linux, after a lot of efforts I found that I had flashed the wrong firmware on the pi pico.
There's one for the raspberry pi and two for the pico, check if you've made my mistake.

DeputyDingles, 2025-05-24:
Confirmed I flashed the **wrong** firmware. Re-flashed the correct Pico specific firmware and everything went flawless! Thank you!

Closed 2025-05-24.

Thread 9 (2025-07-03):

Error: Error connecting DP: cannot read IDR

quasicmatt, 2025-07-03:
when trying to flash the code i get an error cannot read idr tryed with multiple boards and with multiple version of the flashing software as i saw a similar post saying that the software version might be the problem even tried making my own debug program via some steps online incase the pico w was different than pico but no avail is there something im doing wrong?

SL9M, 2025-07-03:
Hi there,

Have you moved the debugprobe_on_pico.uf2 to your pico after holding bootsel?

I assume so, just making sure before going down the rabbit hole.

loopj, 2025-08-08:
Closing due to inactivity

Closed 2025-08-08.

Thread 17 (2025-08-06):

Flashing bootloader and firmware

bryanparadis, 2025-08-06:
Had an interesting time trying to get firmware flashed onto the boards:

Attempt 1: OpenOCD with a st-link v2 and st-link v3 with SWD

OpenOCD doesn't support efm32s2 out of the box looks like there is a third party driver that is available on git though that could be used. I may have to try this again. Is it supposed to work over SWD via the test points on the back? Or this just for debugging?

Attempt 2: probe-rs via st-link v2 and st-link v3

It reads a SWD target

```
Debug Port: DPv2, Designer: Energy Micro, Part: 0x2d41, Revision: 0x0, Instance: 0x00
└── No access ports found on this chip.
```

But it has no access ports and doesn't seem to want to work

Attempt 3: Wavephoenix cli

Tried wavephoenix cli scan but it didn't find anything when powering with pair button held down. I am guessing it would be looking for something specific to the wavephoenix bootloader that I haven't been able to flash

Attempt 4: Simplicity mobile app

I was about to see RFstar_DF8F device and ota firmware update it. It still appears afterwards though after reboot so I have a feeling it's not working as intended.

Attempt 5: probe-rs round 2

Tried again but still no debug ports.

Any ideas what might be amiss? Maybe I will try with efm32s2 support on Linux with a pico running as a debug probe next.

Thanks

bryanparadis, 2025-08-06:
Get unknown error applying OTA update via wavephoenix flash. Gets to 100% and then has that error.

bryanparadis, 2025-08-06:
Cannot use wavephoenix-cli to flash:

```
bryanparadis@pop-os:~/openocd-efm32-series2/openocd$ wavephoenix info
Device information:
- Device Name:              WavePhoenix
- BLE Address:              58:26:3A:3D:DF:8F
- Apploader Version:        070002000000e106
- OTA Version:              03
- Gecko Bootloader Version: 02000402
- Application Version:      00000000
bryanparadis@pop-os:~/openocd-efm32-series2/openocd$ wavephoenix scan
Scanning for WavePhoenix devices...
- Found WavePhoenix device at address: 58:26:3A:3D:DF:8F
bryanparadis@pop-os:~/openocd-efm32-series2/openocd$ wavephoenix flash ~/Downloads/wavephoenix-receiver-v0.9.2-rf-bm-bg22c3.hex
Starting OTA firmware update...

Updating: 100%|████████████████████████████████████████████████████████████████████████████| 157k/157k [00:15<00:00, 10.6kB/s]
Unknown error applying OTA update.
```

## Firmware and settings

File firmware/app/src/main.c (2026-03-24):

#include <stdio.h>
#include <string.h>

#include "btl_interface.h"
#include "em_cmu.h"
#include "em_gpio.h"
#include "em_rmu.h"

#include "sl_main_init.h"
#include "sl_sleeptimer.h"

#include "nvm3_default.h"

#include <joybus/backend/gecko.h>
#include <joybus/joybus.h>

#include "button.h"
#include "status_led.h"
#include "version.h"

#include "input_source/wavebird.h"

// Joybus state
static struct joybus_gecko joybus_gecko;
static struct joybus *joybus = JOYBUS(&joybus_gecko);

// Currently active controller
static struct joybus_gc_controller *active_controller = NULL;

// Pair button
static struct button *pair_button = NULL;

#if HAS_PAIR_BTN
// Begin or end pairing when the pair button is pressed
static void handle_pair_button_press()
{
  input_source_wavebird_handle_button_press();
}

// Reboot into the bootloader when the pair button is held
static void handle_pair_button_hold()
{
  printf("Rebooting into bootloader...\n\n");
  bootloader_rebootAndInstall();
}
#endif

int main(void)
{
  // Initialize the device
  sl_main_init();

  // Enable GPIO clocks
  CMU_ClockEnable(cmuClock_GPIO, true);

  // Check/clear the reset cause
  uint32_t resetCause = RMU_ResetCauseGet();
  RMU_ResetCauseClear();

  // If the debugger caused the reset, delay first to let the probe disconnect
  if (resetCause & EMU_RSTCAUSE_SYSREQ)
    sl_sleeptimer_delay_millisecond(100);

  // Make SWDIO/SWCLK available as a GPIOs
  GPIO_DbgSWDIOEnable(false);
  GPIO_DbgSWDClkEnable(false);

  // Initialize NVM driver for settings storage
  nvm3_initDefault();

  // Initialize the pair button, if present
#if HAS_PAIR_BTN
  static struct button _pair_button;
  pair_button = &_pair_button;
  button_init(pair_button, PAIR_BTN_PORT, PAIR_BTN_PIN);
  button_set_press_callback(pair_button, handle_pair_button_press);
  button_set_long_press_callback(pair_button, handle_pair_button_hold);
#endif

  // Initialize status LED, if present
  status_led_init();

  // Initialize WaveBird input source
  input_source_wavebird_init();
  active_controller = input_source_wavebird_get_controller();

  // Initialize Joybus
  joybus_gecko_init(&joybus_gecko, JOYBUS_PORT, JOYBUS_PIN, JOYBUS_TIMER, JOYBUS_USART);
  joybus_target_register(joybus, JOYBUS_TARGET(active_controller));

  // Enable Joybus
  joybus_enable(joybus);

  // Lets-a-go!
  printf("WavePhoenix receiver v%d.%d.%d ready!\n", VERSION_MAJOR, VERSION_MINOR, VERSION_PATCH);

  // Main loop
  while (1) {
    // Check for new wavebird inputs
    input_source_wavebird_process();

    // Update status LED
    status_led_update();
  }
}

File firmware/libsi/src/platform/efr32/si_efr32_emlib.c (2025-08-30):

#include <stddef.h>

#include "em_cmu.h"
#include "em_gpio.h"
#include "em_ldma.h"
#include "em_timer.h"
#include "em_usart.h"

#include "dmadrv.h"

#include "si/device/commands.h"

#ifdef __ZEPHYR__
#include <zephyr/irq.h>
#endif

// RX TIMER peripheral configuration
#ifndef SI_RX_TIMER_IDX
#define SI_RX_TIMER_IDX         0
#endif

#if SI_RX_TIMER_IDX == 0
#define SI_RX_TIMER             TIMER0
#define SI_RX_TIMER_CLK         cmuClock_TIMER0
#define SI_RX_LDMA_SIGNAL       ldmaPeripheralSignal_TIMER0_CC0
#elif SI_RX_TIMER_IDX == 1
#define SI_RX_TIMER             TIMER1
#define SI_RX_TIMER_CLK         cmuClock_TIMER1
#define SI_RX_LDMA_SIGNAL       ldmaPeripheralSignal_TIMER1_CC0
#elif SI_RX_TIMER_IDX == 2
#define SI_RX_TIMER             TIMER2
#define SI_RX_TIMER_CLK         cmuClock_TIMER2
#define SI_RX_LDMA_SIGNAL       ldmaPeripheralSignal_TIMER2_CC0
#elif SI_RX_TIMER_IDX == 3
#define SI_RX_TIMER             TIMER3
#define SI_RX_TIMER_CLK         cmuClock_TIMER3
#define SI_RX_LDMA_SIGNAL       ldmaPeripheralSignal_TIMER3_CC0
#else
#error "Invalid SI_RX_TIMER_IDX value"
#endif

// TX USART peripheral configuration
#ifndef SI_TX_USART_IDX
#define SI_TX_USART_IDX         0
#endif

#if SI_TX_USART_IDX == 0
#define SI_TX_USART             USART0
#define SI_TX_USART_CLK         cmuClock_USART0
#define SI_TX_USART_IRQn        USART0_TX_IRQn
#define SI_TX_USART_IRQHandler  USART0_TX_IRQHandler
#define SI_TX_LDMA_SIGNAL       ldmaPeripheralSignal_USART0_TXBL
#elif SI_TX_USART_IDX == 1
#define SI_TX_USART             USART1
#define SI_TX_USART_CLK         cmuClock_USART1
#define SI_TX_USART_IRQn        USART1_TX_IRQn
#define SI_TX_USART_IRQHandler  USART1_TX_IRQHandler
#define SI_TX_LDMA_SIGNAL       ldmaPeripheralSignal_USART1_TXBL
#else
#error "Invalid SI_TX_USART_IDX value"
#endif

// Number of chips per bit for the line coding
#define CHIPS_PER_BIT           4

// Line coding
#define BIT_0                   0b0001
#define BIT_1                   0b0111
#define DEVICE_STOP             0b00111111
#define HOST_STOP               0b01111111

// SI bus idle period (in microseconds)
#define BUS_IDLE_US             100

// RX buffer size (16 edges per byte)
#define RX_BUFFER_SIZE          16

// TX buffer size (4 chips per bit, extra byte for stop bit)
#define TX_BUFFER_SIZE          (SI_BLOCK_SIZE * CHIPS_PER_BIT + 1)

// SI configuration
static uint8_t si_data_port;
static uint8_t si_data_pin;
static bool si_mode;
static bool si_initialized = false;

// RX state
static uint16_t rx_edge_timings[2][RX_BUFFER_SIZE];
static uint16_t rx_pulse_period_half;
static uint16_t rx_bus_idle_period;
static unsigned int rx_dma_channel;

// TX State
static uint8_t tx_buffer[TX_BUFFER_SIZE];
static unsigned int tx_dma_channel;

// Transfer state
static struct {
  uint8_t *data;
  uint8_t max_length;
  si_byte_cb_t byte_callback;
  si_complete_cb_t complete_callback;
} si_xfer;

// RX LDMA configuration
static LDMA_TransferCfg_t ldma_rx_config       = LDMA_TRANSFER_CFG_PERIPHERAL(SI_RX_LDMA_SIGNAL);
static LDMA_Descriptor_t ldma_rx_descriptors[] = {
    LDMA_DESCRIPTOR_LINKREL_P2M_WORD(&SI_RX_TIMER->CC[0].ICF, &rx_edge_timings[0], RX_BUFFER_SIZE, 1),
    LDMA_DESCRIPTOR_LINKREL_P2M_WORD(&SI_RX_TIMER->CC[0].ICF, &rx_edge_timings[1], RX_BUFFER_SIZE, -1),
};

// TX LDMA configuration
static LDMA_TransferCfg_t ldma_tx_config       = LDMA_TRANSFER_CFG_PERIPHERAL(SI_TX_LDMA_SIGNAL);
static LDMA_Descriptor_t ldma_tx_descriptors[] = {
    LDMA_DESCRIPTOR_SINGLE_M2P_BYTE(tx_buffer, &(SI_TX_USART->TXDATA), 1),
};

static void init_rx(uint8_t port, uint8_t pin, uint32_t freq);
static void init_tx(uint8_t port, uint8_t pin, uint32_t freq);
static uint8_t *encode_byte(uint8_t *dest, uint8_t src);
static void decode_edge_timings(uint8_t *dest, uint16_t *src);
static bool ldma_callback_rx(unsigned int chan, unsigned int iteration, void *user_data);

void si_init(uint8_t port, uint8_t pin, uint8_t mode, uint32_t rx_freq, uint32_t tx_freq)
{
  // Initialize LDMA
  DMADRV_Init();

  // Use the HFXO as the TIMER clock source
  CMU_ClockSelectSet(cmuClock_EM01GRPACLK, cmuSelect_HFXO);

  // Enable clocks
  CMU_ClockEnable(cmuClock_GPIO, true);

  // Set the SI data line as open-drain output
  GPIO_PinModeSet(port, pin, gpioModeWiredAnd, 1);

  // Adjust size of rx transfer size to half-word
  ldma_rx_descriptors[0].xfer.size = ldmaCtrlSizeHalf;
  ldma_rx_descriptors[1].xfer.size = ldmaCtrlSizeHalf;

  // Initialize SI RX and TX
  init_rx(port, pin, rx_freq);
  init_tx(port, pin, tx_freq);

  // Save the SI configuration
  si_data_port = port;
  si_data_pin  = pin;
  si_mode      = mode;

  si_initialized = true;
}

void si_write_bytes(const uint8_t *bytes, uint8_t length, si_complete_cb_t callback)
{
  // Save the transfer state
  si_xfer.data              = (uint8_t *)bytes;
  si_xfer.max_length        = length;
  si_xfer.byte_callback     = NULL;
  si_xfer.complete_callback = callback;

  // Convert the bytes to appropriate line coding and add to the buffer
  uint8_t *buf_ptr = tx_buffer;
  for (int i = 0; i < length; i++)
    buf_ptr = encode_byte(buf_ptr, bytes[i]);

  // Add the stop bit
  *buf_ptr++ = (si_mode == SI_MODE_HOST ? HOST_STOP : DEVICE_STOP);

  // Set the transfer count (xferCnt expects the number of transfer minus one)
  ldma_tx_descriptors[0].xfer.xferCnt = (length * CHIPS_PER_BIT + 1) - 1;

  // Start the DMA transfer
  DMADRV_LdmaStartTransfer(tx_dma_channel, &ldma_tx_config, ldma_tx_descriptors, NULL, NULL);
}

void si_read_bytes(uint8_t *buffer, uint8_t max_length, si_byte_cb_t byte_callback, si_complete_cb_t complete_callback)
{
  // Save the transfer state
  si_xfer.data              = buffer;
  si_xfer.max_length        = max_length;
  si_xfer.byte_callback     = byte_callback;
  si_xfer.complete_callback = complete_callback;

  // Clear the RX buffer
  while (TIMER_CaptureGet(SI_RX_TIMER, 0))
    ;

  // Start the input capture timer
  TIMER_Enable(SI_RX_TIMER, true);

  // Start the LDMA transfer
  DMADRV_LdmaStartTransfer(rx_dma_channel, &ldma_rx_config, ldma_rx_descriptors, ldma_callback_rx, NULL);
}

void si_await_bus_idle(void)
{
  // Start the timer
  TIMER_Enable(SI_RX_TIMER, true);

  while (1) {
    // Wait for the line to go high
    // TODO: Add a timeout
    while (GPIO_PinInGet(si_data_port, si_data_pin) == 0)
      ;

    // Start timing the bus idle period
    TIMER_CounterSet(SI_RX_TIMER, 0);

    // Wait for either the bus idle period to elapse or line to go low
    // TODO: Add a timeout
    while (GPIO_PinInGet(si_data_port, si_data_pin) == 1) {
      if (TIMER_CounterGet(SI_RX_TIMER) >= rx_bus_idle_period)
        goto idle_detected;
    }
  }

idle_detected:
  // Stop the timer
  TIMER_Enable(SI_RX_TIMER, false);
}
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

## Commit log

2025-04-25 Initial release
    [BOM-mini-receiver.csv, Button Actuator.stl, CONN-SMD_SR1.00-WS-4P.step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]
2025-04-25 Update BOM links for GameCube male connector
2025-06-30 WIP new module support on boards
    [CONN-SMD_SR1.00-WS-4P.step, KEY-SMD_4P-L5.2-W5.2-H1.5-LS6.4-P3.70.step, LED0805-RD.step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]
2025-07-10 Recommend the Arduino fork of openocd instead of mine, since it has prebuilt binaries
2025-07-11 Rename the libsi efr32 driver
2025-07-16 Don't invert USART TX, use tristate instead
    [si_efr32_emlib.c]
2025-08-05 Fix auto tx->rx transition
    [main.c]
2025-08-09 libsi: Add helper function to test if device is wireless
2025-08-11 Ensure need_origin flag is set correctly in both wired and wireless modes
    [main.c]
2025-09-10 Fix 'probe device' handling for launch window games
2025-09-10 Add test for probe_device changes
2026-01-08 Rail config generation script, add other configs
2026-01-12 Share board configs between bootloader and app firmware, drop cmake
2026-01-14 Split out RF-BM-BG22C3 board config, define a Mini Receiver board
2026-03-24 Abstract out status LED to allow for different effects on future boards
2026-03-24 Drop channel wheel support
2026-03-24 Move libwavebird <-> libjoybus glue layer into own file

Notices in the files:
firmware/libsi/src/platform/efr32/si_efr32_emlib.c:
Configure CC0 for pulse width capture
